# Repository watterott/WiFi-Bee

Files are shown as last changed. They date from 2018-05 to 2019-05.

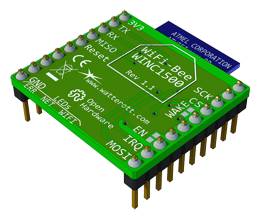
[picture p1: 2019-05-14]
hardware/WiFi-Bee_v11.jpg

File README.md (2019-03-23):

# WiFi-Bee
XBee footprint compatible WiFi/WLAN Module with Microchip ATWINC1500 WiFi Network Controller.

* [Microchip ATWINC1500](https://www.microchip.com/wwwproducts/en/ATWINC1500) WiFi Network Controller
* Integrated WiFi and IPv4 stack
* SPI interface
* XBee compatible Pinout (3.3V)
* Open-Source and released under the [Creative Commons Attribution Share-Alike License](https://creativecommons.org/licenses/by-sa/4.0/).
* **[Documentation on learn.watterott.com](https://learn.watterott.com)**

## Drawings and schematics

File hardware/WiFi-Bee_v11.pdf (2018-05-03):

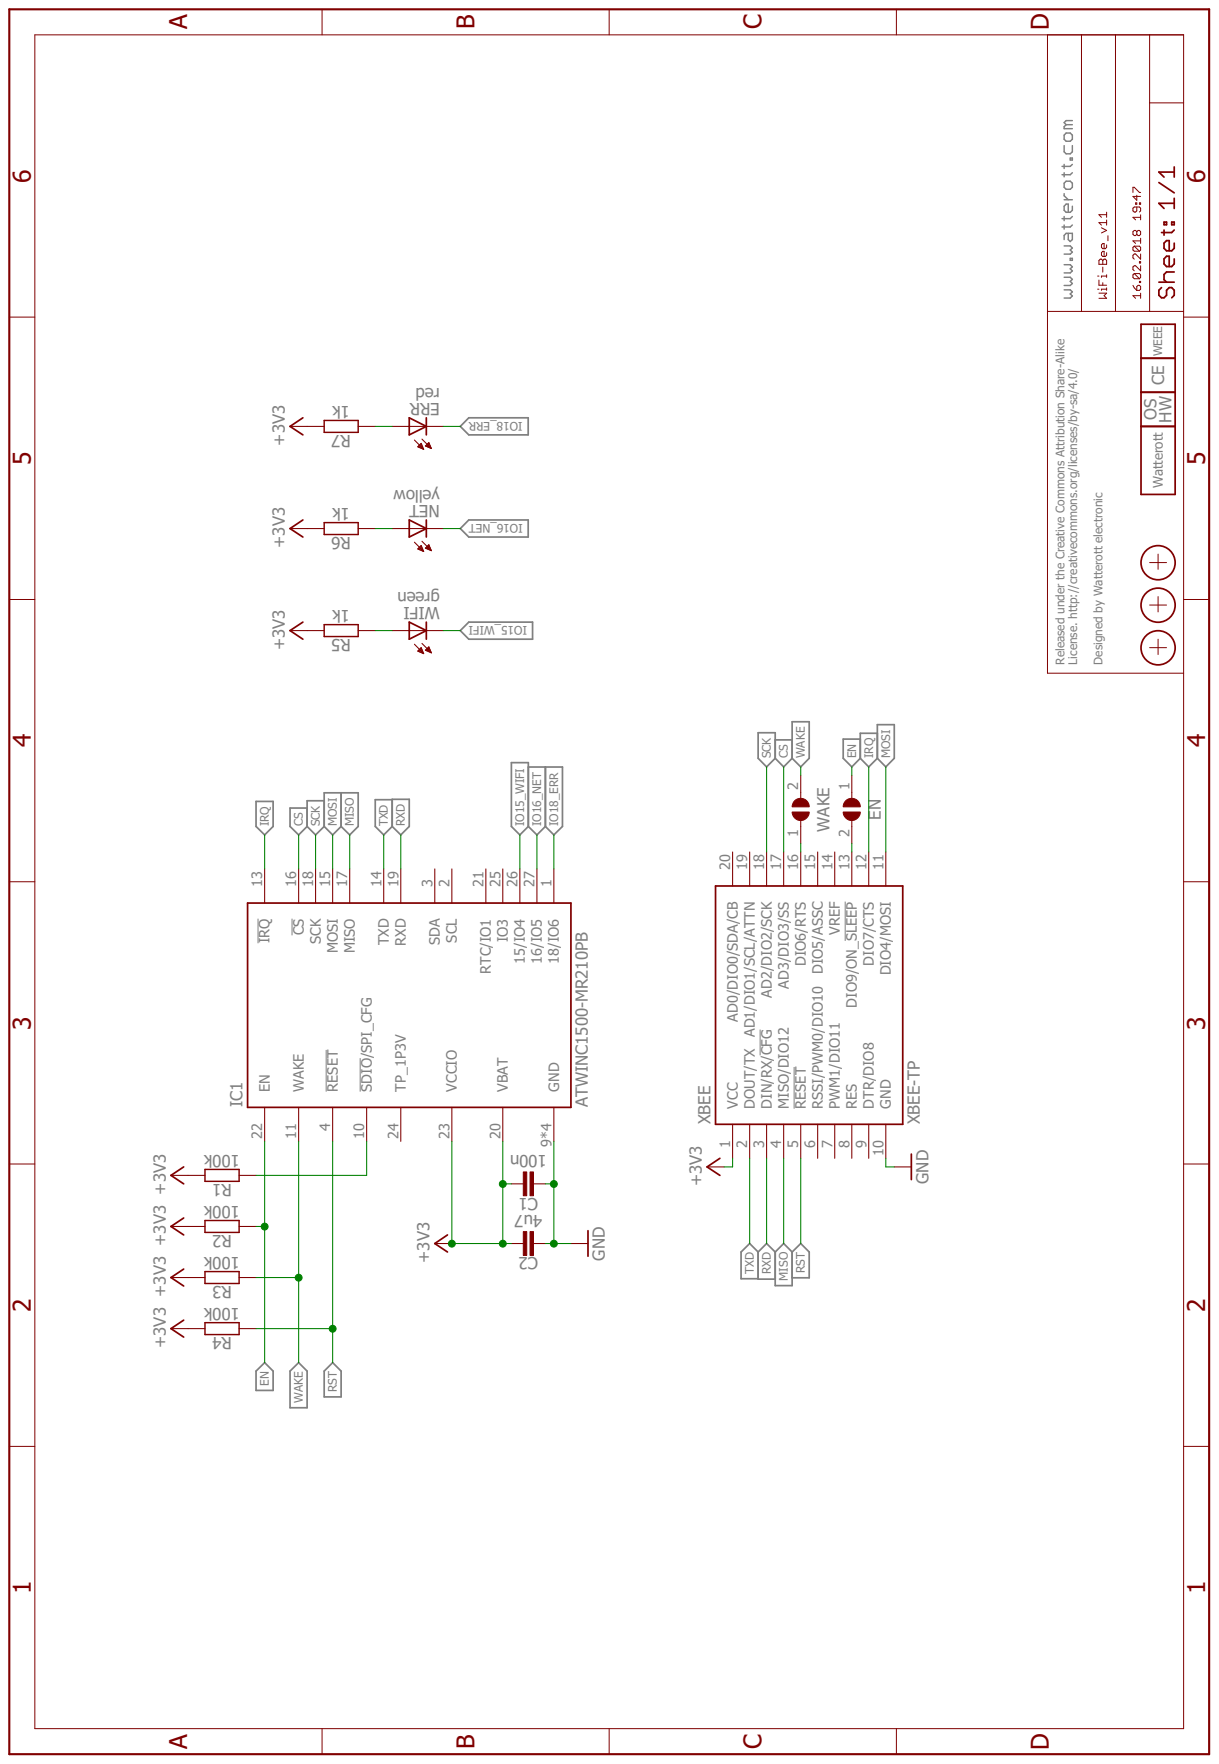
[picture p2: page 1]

Watterott OS HW CE WEEE

Released under the Creative Commons Attribution Share-Alike

License. http://creativecommons.org/licenses/by-sa/4.0/ Designed by Watterott electronic

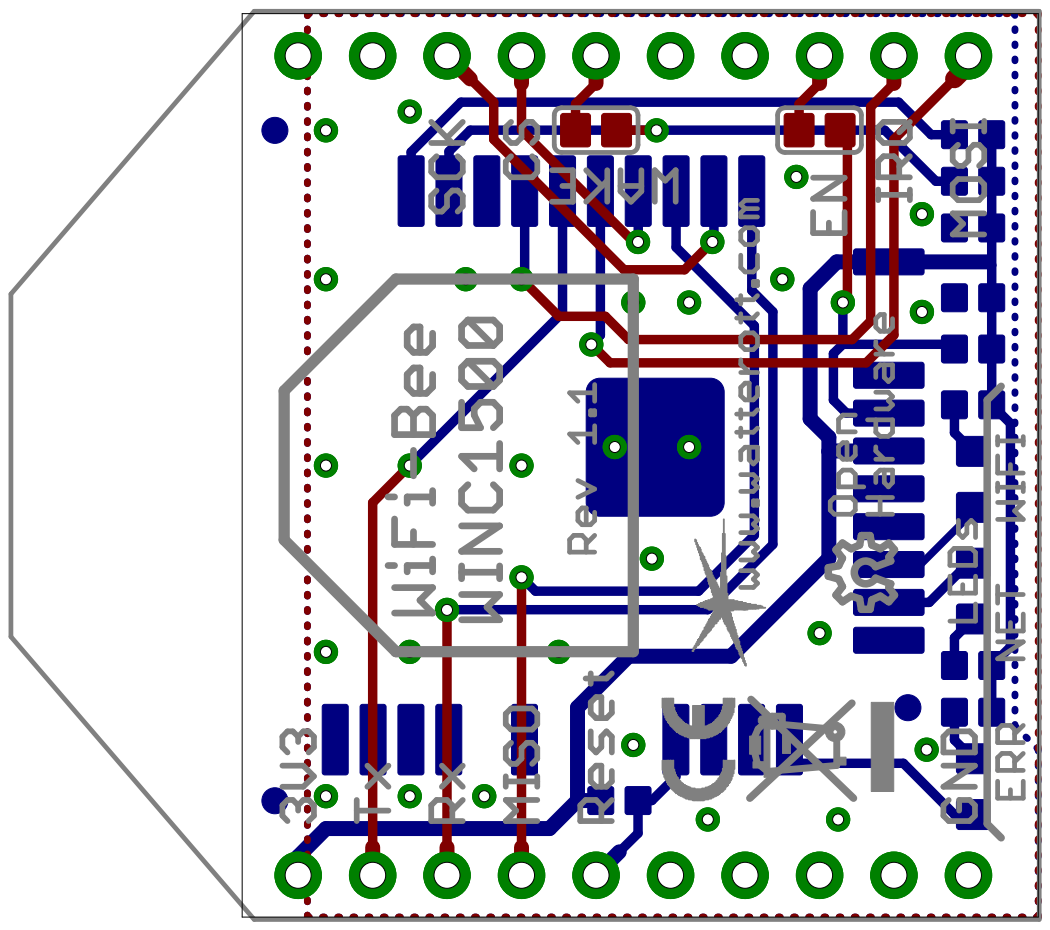
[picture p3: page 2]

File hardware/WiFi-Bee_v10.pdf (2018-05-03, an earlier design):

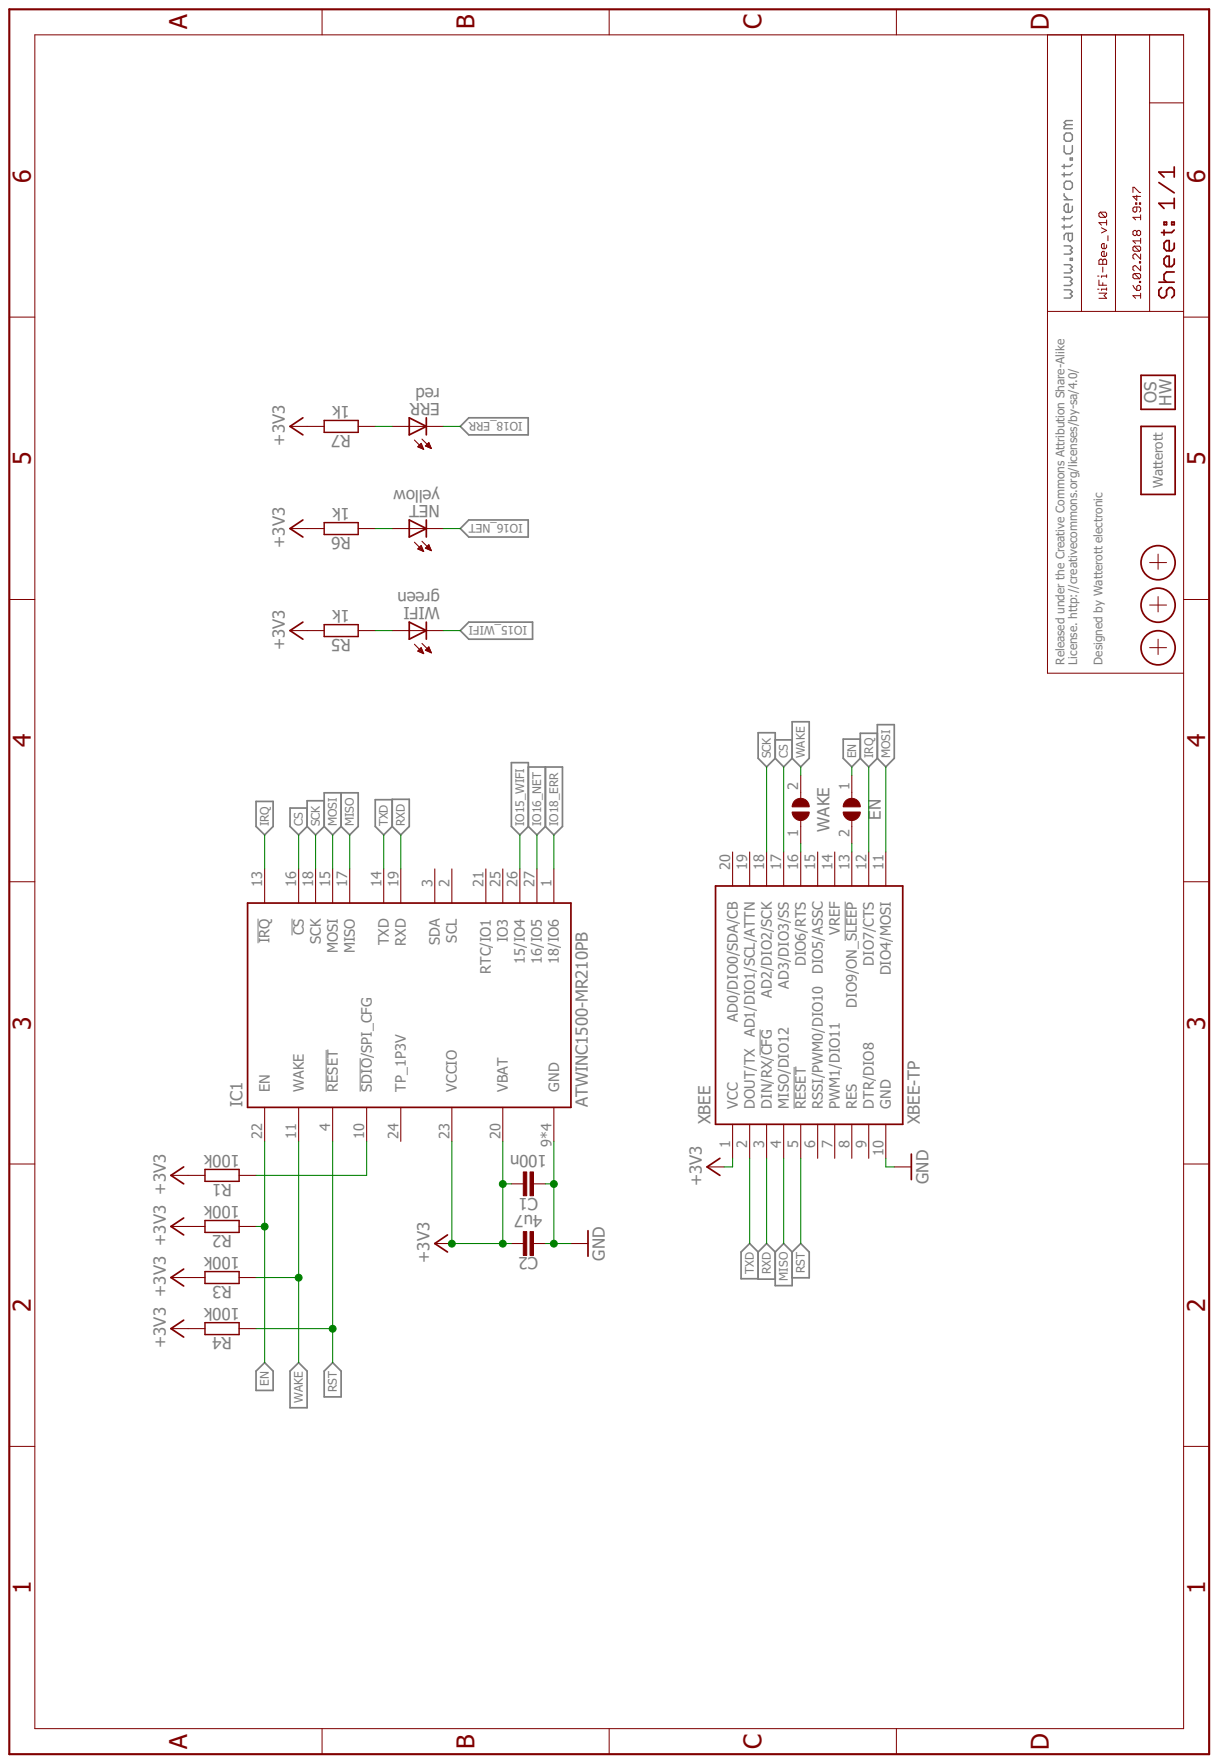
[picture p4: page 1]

Released under the Creative Commons Attribution Share-Alike

License. http://creativecommons.org/licenses/by-sa/4.0/ Designed by Watterott electronic

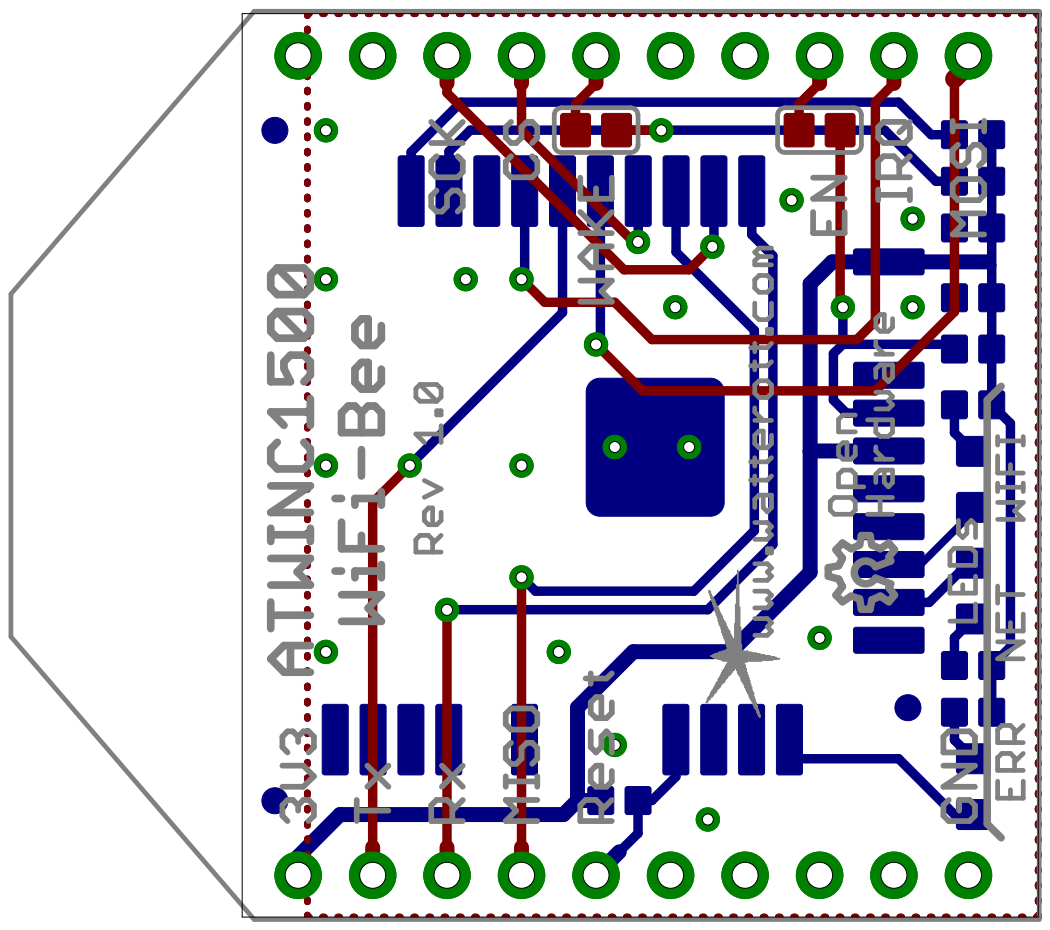
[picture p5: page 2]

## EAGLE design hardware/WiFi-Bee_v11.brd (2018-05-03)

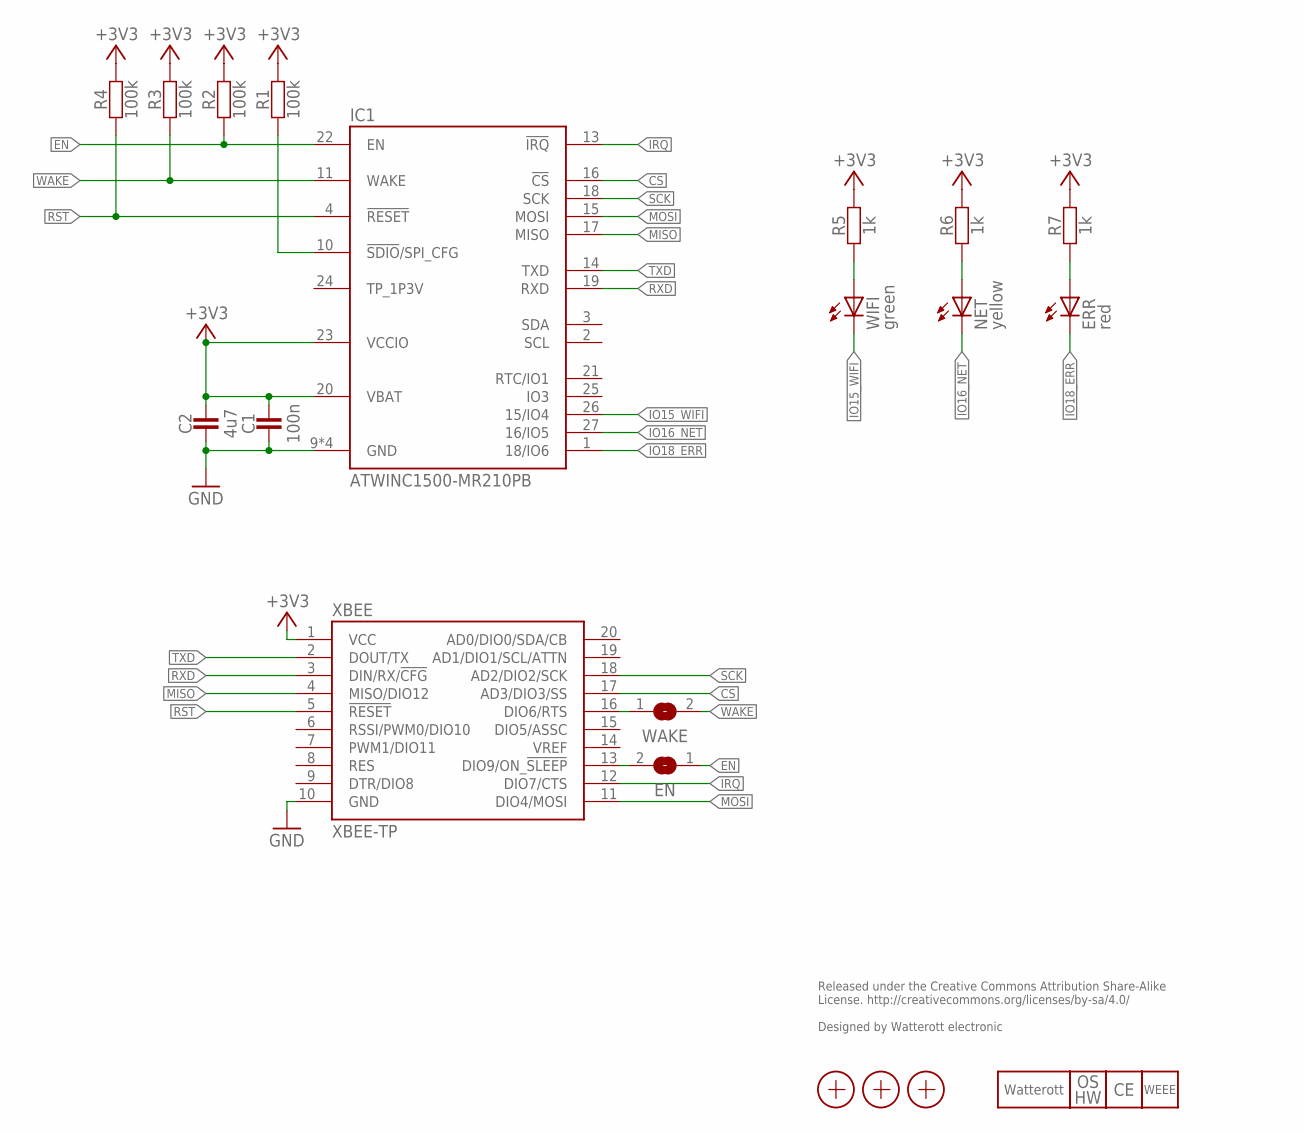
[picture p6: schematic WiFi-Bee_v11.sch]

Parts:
C1: 100n; C0402
C2: 4u7; C0402
EN: JUMPER2-0402
ERR: red; C0603
IC1: ATWINC1500-MR210PB; ATWINC1500-MX210
LOGO1: LOGO_CE-2; CE_2MM
LOGO2: LOGO_WEEE-4; WEEE_4MM
LOGO3: LOGO_SPARK-2; SPARK_2MM
LOGO4: LOGO_OSHW-2; OSHW_2MM
NET: yellow; C0603
R1, R2, R3, R4: 100k; C0402
R5, R6, R7: 1k; C0402
WAKE: JUMPER2-0402
WIFI: green; C0603
X1, X2, X3: PASSER-07; PASSER_07MM
XBEE: XBEE-TP; XBEE_TP

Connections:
+3V3: C1.2, C2.2, IC1.20 (VBAT), IC1.23 (VCCIO), R1.2, R2.2, R3.2, R4.2, R5.2, R6.2, R7.2, XBEE.1 (VCC)
CFG: IC1.10 (!SDIO!/SPI_CFG), R1.1
CS: IC1.16 (!CS), XBEE.17 (AD3/DIO3/SS)
EN: EN.1, IC1.22 (EN), R2.1
EN2: EN.2, XBEE.13 (DIO9/ON_!SLEEP!)
GND: C1.1, C2.1, IC1.9 (GND), IC1.12 (GND), IC1.28 (GND), IC1.GND, XBEE.10 (GND)
IO15_WIFI: IC1.26 (15/IO4), WIFI.C
IO16_NET: IC1.27 (16/IO5), NET.C
IO18_ERR: ERR.C, IC1.1 (18/IO6)
IRQ: IC1.13 (!IRQ), XBEE.12 (DIO7/CTS)
LEDE: ERR.A, R7.1
LEDN: NET.A, R6.1
LEDW: R5.1, WIFI.A
MISO: IC1.17 (MISO), XBEE.4 (MISO/DIO12)
MOSI: IC1.15 (MOSI), XBEE.11 (DIO4/MOSI)
RST: IC1.4 (!RESET), R4.1, XBEE.5 (!RESET!)
RXD: IC1.19 (RXD), XBEE.3 (DIN/RX/!CFG!)
SCK: IC1.18 (SCK), XBEE.18 (AD2/DIO2/SCK)
TXD: IC1.14 (TXD), XBEE.2 (DOUT/TX)
WAKE: IC1.11 (WAKE), R3.1, WAKE.2
WAKE1: WAKE.1, XBEE.16 (DIO6/RTS)

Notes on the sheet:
Released under the Creative Commons Attribution Share-Alike License. http://creativecommons.org/licenses/by-sa/4.0/ Designed by Watterott electronic

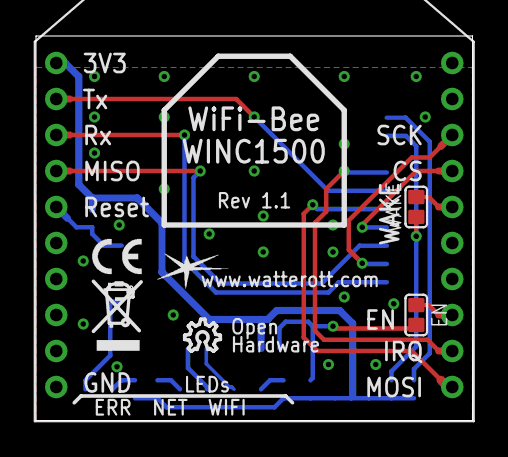
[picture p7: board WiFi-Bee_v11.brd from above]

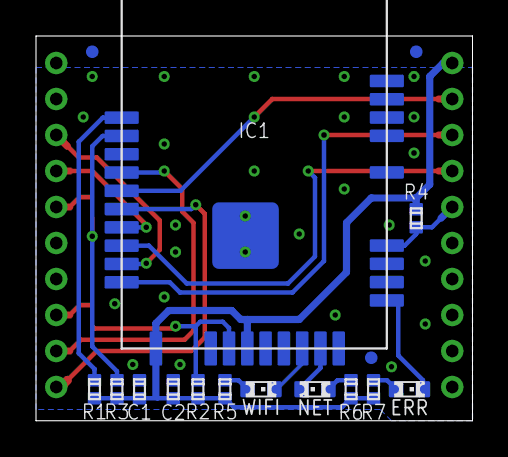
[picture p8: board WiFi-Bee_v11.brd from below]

Board: 2 copper layers, 24.2 x 21.4 mm, 23 parts (16 on the bottom side), 21 nets.
